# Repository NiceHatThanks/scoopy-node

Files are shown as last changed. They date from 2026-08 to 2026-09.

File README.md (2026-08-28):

# Scoopy Node

Tiny, local-first room hardware for Home Assistant and ESPHome.

Scoopy is a compact USB-C powered room controller built around an ESP32-C3. V1 combines two physical buttons, three PWM LEDs, optional LD2410C mmWave presence sensing, optional Home Assistant Bluetooth Proxy support, and an I²C expansion connection in a small 3D-printed enclosure.

There are two enclosure variants:

- **Scoopy Presence** — the full-size enclosure with an LD2410C mmWave presence sensor.
- **Scoopy Compact** — the smaller enclosure without the radar.

Both variants use the same firmware image. If an LD2410C is not fitted, the rest of Scoopy continues to work normally.

This repository contains the source-available hardware files, versioned STL enclosure exports, ESPHome firmware, captive-portal UI, manufacturing outputs, and project documentation.

## Quick links

- Website and product information: https://nicehatthanks.com
- First-time setup: https://nicehatthanks.com/setup/
- Interactive Home Assistant docs and examples: https://nicehatthanks.com/docs/
- Assembly guide: [`docs/assembly.md`](docs/assembly.md)
- Troubleshooting: [`docs/troubleshooting.md`](docs/troubleshooting.md)
- Bambu Studio / 3MF project: [Scoopy on MakerWorld](https://makerworld.com/en/models/3231250-scoopy-home-assistant-esphome-room-controller#profileId-3659818)

## Repository structure

```text
hardware/
  kicad/             Editable KiCad source files
  gerbers/           Fabrication-ready Gerbers and drill files
  bom/               Bill of materials and manufacturing exports

enclosure/
  compact/           Versioned STL exports for Scoopy Compact
  presence/          Versioned STL exports for Scoopy Presence
  build/             Assembly photos used by the build guide

firmware/
  esphome/           Unified ESPHome configuration and custom components
  captive-portal/    Source for the branded Wi-Fi setup page

docs/
  setup.md           First-time setup and Home Assistant pairing
  examples.md        Ready-made Home Assistant automations
  assembly.md        V1 enclosure assembly guide
  troubleshooting.md Common setup, firmware and hardware issues
```

## Firmware

`firmware/esphome/scoopy.yaml` is the unified production configuration for both Scoopy variants. The V1 firmware identifies itself as `1.0.0` through the ESPHome project version.

V1 features include:

- Unique `scoopy-XXXXXX` naming using the ESP32 MAC address
- Scoopy-branded local Wi-Fi provisioning with a captive portal
- ESPHome native API and Home Assistant discovery
- Two physical buttons exposed as `single`, `double`, and `hold` event entities
- Three individually dimmable PWM LED entities
- Individual pulse, flash, and alert LED effects
- Coordinated three-LED patterns including Circular Pulse, Comet, Breathe All, Heartbeat, Ping Pong, and Ripple
- Pulsing red Wi-Fi/setup indication and a brief green confirmation after connection
- LD2410C presence, moving-target, and still-target entities when the radar is fitted
- Optional Home Assistant Bluetooth Proxy, disabled by default
- Passive BLE scanning with one active proxy connection slot
- Website-hosted firmware updates through the Home Assistant **Firmware Update** entity
- Native ESPHome OTA support for local/development updates
- USB serial provisioning through Improv
- Wi-Fi signal, Wi-Fi percentage, IP address, uptime, ESPHome version, and Scoopy firmware diagnostics
- I²C expansion on GPIO5 (SDA) and GPIO7 (SCL)
- Physical Wi-Fi/factory recovery by holding both buttons for 10 seconds

The firmware deliberately uses one image for both variants. On Scoopy Compact, LD2410C entities may show as unavailable or Unknown because the radar is not fitted; this does not affect buttons, LEDs, Wi-Fi, OTA, Bluetooth Proxy, or the rest of the device.

## Home Assistant

Once Scoopy has joined the same network as Home Assistant, ESPHome discovery should find it automatically.

Ready-made automations are in [`docs/examples.md`](docs/examples.md). The examples cover:

- LED pattern control
- Button-controlled lighting
- Presence-controlled lighting
- Time-aware lighting
- Alarm reminders
- Status LEDs
- Multi-function room controls for lights, fans, and blinds

The interactive version at https://nicehatthanks.com/docs/ can take one of your Scoopy Entity IDs and fill the matching Scoopy prefix into the examples automatically.

## Setup and recovery

For normal first-time setup, use https://nicehatthanks.com/setup/ or [`docs/setup.md`](docs/setup.md).

A fresh or factory-reset Scoopy creates a Wi-Fi network named `scoopy-XXXXXX` with password `scoopy123`. Wi-Fi credentials are sent directly to Scoopy through its local setup page; no Scoopy cloud account is involved.

To clear saved Wi-Fi credentials and return to setup mode, hold both physical buttons together for 10 seconds. The middle red LED flashes rapidly near the end of the hold before the reset is performed.

## Firmware updates

Released firmware can be installed directly from Home Assistant through Scoopy's **Firmware Update** entity. Scoopy reads the update manifest hosted at:

`https://nicehatthanks.com/firmware/scoopy/manifest.json`

An OTA update preserves the device identity, saved Wi-Fi credentials, Home Assistant connection, and existing entity IDs.

## Enclosure and printing

GitHub contains the versioned raw STL exports for Scoopy Compact and Scoopy Presence.

The slicer-ready Bambu Studio / 3MF project is intentionally **not** duplicated in this repository. MakerWorld is the single maintained source for the Bambu project and print profile:

**[Scoopy on MakerWorld](https://makerworld.com/en/models/3231250-scoopy-home-assistant-esphome-room-controller#profileId-3659818)**

See [`enclosure/README.md`](enclosure/README.md) for the STL layout and [`docs/assembly.md`](docs/assembly.md) for assembly.

## Hardware overview

V1 uses a 28 × 28 mm carrier PCBA with:

- ESP32-C3 Super Mini
- 2 × tactile buttons
- 3 × LEDs with 2.2 kΩ series resistors
- Optional HLK-LD2410C mmWave presence sensor
- I²C expansion connection
- USB-C power through the ESP32-C3 module

Scoopy Presence uses the LD2410C and the larger enclosure. Scoopy Compact uses the same carrier and firmware without the radar.

Electrical design and manufacturing files are documented in [`hardware/README.md`](hardware/README.md).

## Assembly

The enclosure build is the same basic process for Compact and Presence: fit the heat-set insert, secure the PCBA, place the two buttons in the lid, then clip the base and lid together while aligning the three light pipes with the LEDs.

For Scoopy Presence, a nylon M2 screw is recommended near the LD2410C because a metal screw may affect the radar.

See the illustrated [`docs/assembly.md`](docs/assembly.md) guide.

## Release status

`v1.0.0` is the first formal Scoopy release. The V1 hardware, firmware, STL exports, documentation, and manufacturing files in that release tag form the reproducible V1 baseline.

Development on `main` may move ahead after the release. Use a release tag when reproducing a known version.

## Build your own

The hardware, firmware, and printable STL files are available so you can inspect Scoopy, build one for yourself, modify it, and experiment with your own non-commercial versions.

Commercial manufacture or sale requires prior permission from Nice Hat Thanks.

See [`LICENSE`](LICENSE) for the full terms.

## Licence

Scoopy is **source available for personal and non-commercial use**. You may inspect the files, build your own, modify them, and share non-commercial derivatives under the terms in [`LICENSE`](LICENSE).

Commercial manufacture, sale, or other commercial use requires prior written permission from Nice Hat Thanks.

Scoopy is not released under an open-source or open-hardware licence.

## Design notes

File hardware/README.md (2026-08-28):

# Hardware

Electrical design and manufacturing files for Scoopy Node.

## Structure

- `kicad/scoopy/` — editable KiCad project source
- `gerbers/v1/` — V1 fabrication-ready Gerber and drill files
- `gerbers/V1-Gerbers.zip` — upload-ready V1 Gerber archive
- `bom/v1/` — V1 bill of materials and manufacturing exports

The KiCad directory contains the editable design source. Generated fabrication outputs live separately so the project stays clean and manufacturing files are easy to identify.

Exported schematic PDFs are not currently committed as a separate directory. The editable schematic is part of the KiCad project; release-specific exports can be added when useful.

Third-party STEP/GLB models and standalone library components with redistribution restrictions are intentionally not included.

## Revisions

Manufacturing outputs should remain grouped by hardware revision (`v1/`, `v2/`, and so on). Releases and Git tags can then identify the exact set of files used for a known hardware build.

`v1.0.0` identifies the first production-frozen V1 hardware baseline. Development on `main` may continue after that tag, so use a release/tag when reproducing a known hardware build.

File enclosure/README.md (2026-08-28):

# Enclosure

Printable enclosure files for Scoopy Node.

Scoopy has two enclosure variants:

- `compact/` — the smaller enclosure without presence sensing
- `presence/` — the larger enclosure designed for the mmWave presence version

Each variant is organised the same way:

```text
<variant>/
  stl/
    v1/
      full/      complete enclosure STL export
      parts/     individual printable components
```

## Bambu Studio / 3MF project

The slicer-ready Bambu Studio / 3MF project is intentionally **not** tracked in this repository.

MakerWorld is the single maintained source for the Bambu project and print profile:

**[Scoopy on MakerWorld](https://makerworld.com/en/models/3231250-scoopy-home-assistant-esphome-room-controller#profileId-3659818)**

This avoids having separate GitHub and MakerWorld copies drift apart over time. GitHub remains the source for the versioned raw STL exports; MakerWorld is the source for the maintained Bambu slicer project/profile.

Fusion source files are intentionally not published. The public enclosure files are focused on making it straightforward to print a complete enclosure or replace individual parts.

Keep printable STL exports grouped by enclosure revision so a known release can always be reproduced later.

## V1 filenames

The committed V1 exports use these names:

```text
scoopy-compact-v1-complete.stl
scoopy-compact-v1-base.stl
scoopy-compact-v1-lid.stl
scoopy-compact-v1-button1.stl
scoopy-compact-v1-button2.stl
scoopy-compact-v1-lightpipe-1.stl
scoopy-compact-v1-lightpipe-2.stl
scoopy-compact-v1-lightpipe-3.stl

scoopy-presence-v1-complete.stl
scoopy-presence-v1-base.stl
scoopy-presence-v1-lid.stl
scoopy-presence-v1-button1.stl
scoopy-presence-v1-button2.stl
scoopy-presence-v1-lightpipe-1.stl
scoopy-presence-v1-lightpipe-2.stl
scoopy-presence-v1-lightpipe-3.stl
```

For assembly, see [`../docs/assembly.md`](../docs/assembly.md).

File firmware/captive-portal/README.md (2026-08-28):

# Captive portal

This directory contains the human-readable source for Scoopy's branded first-time Wi-Fi setup page.

## Files

- `index.html` — standalone source for the Scoopy captive-portal UI

The production ESPHome firmware uses a local captive-portal component under `../esphome/components/` so ESPHome's normal provisioning behaviour can be retained while presenting the Scoopy setup UI.

## Relationship to the firmware

The production device configuration lives in `../esphome/scoopy.yaml`.

On a fresh or factory-reset device, Scoopy creates a `scoopy-XXXXXX` Wi-Fi access point. After the user connects, the captive portal is used to select the home Wi-Fi network and provide its credentials.

The production firmware deliberately does not compile a customer's Wi-Fi credentials into the image.

The V1 provisioning flow has been validated on hardware for first-time setup and recovery and is part of the `v1.0.0` firmware baseline.

## Editing

Treat `index.html` as the human-readable source for the setup page. The copy served by firmware is embedded in `../esphome/components/captive_portal/scoopy_index.h`.

When changing the captive-portal UI, keep the human-readable HTML and embedded firmware copy in sync, then re-test both fresh-device onboarding and the 10-second physical factory-reset flow before releasing the change.

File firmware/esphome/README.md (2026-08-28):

# ESPHome firmware

This directory contains the unified ESPHome production firmware for Scoopy.

Scoopy Presence and Scoopy Compact use the same `scoopy.yaml` configuration. Scoopy Presence includes the LD2410C mmWave radar; Scoopy Compact omits it. When no LD2410C is fitted, the rest of the device continues to operate normally.

## Files

- `scoopy.yaml` — unified production ESPHome configuration
- `components/` — local ESPHome component overrides used by Scoopy
- `.gitignore` — prevents local ESPHome build output and secrets from being committed

The human-readable branded captive-portal HTML source is kept separately in `../captive-portal/`.

## Pinout

| GPIO | Function |
| --- | --- |
| GPIO0 | ESP RX ← LD2410C TX |
| GPIO1 | ESP TX → LD2410C RX |
| GPIO2 | Button 1 |
| GPIO3 | Button 2 |
| GPIO4 | Left green LED |
| GPIO5 | I²C SDA |
| GPIO6 | Middle red LED |
| GPIO7 | I²C SCL |
| GPIO10 | Right green LED |

## First-time provisioning

A fresh or factory-reset Scoopy starts its own Wi-Fi access point named `scoopy-XXXXXX`, where the suffix comes from the ESP32 MAC address.

1. Power Scoopy over USB-C.
2. Connect to the `scoopy-XXXXXX` Wi-Fi network.
3. Use the setup password `scoopy123`.
4. Enter the home Wi-Fi credentials in the Scoopy captive portal.
5. After Scoopy joins Wi-Fi, the red setup indication stops and both green LEDs give a brief confirmation flash.
6. Home Assistant should then discover Scoopy through the ESPHome integration.

Provisioning over USB serial using ESPHome Improv is also enabled.

## Recovery

Hold both physical buttons together for 10 seconds to clear the saved Wi-Fi credentials and return Scoopy to setup mode. The middle red LED flashes rapidly near the end of the hold before the reset is performed.

## Firmware behaviour

The V1 production configuration provides:

- MAC-suffixed `scoopy-XXXXXX` device names so one firmware image can be flashed to multiple units
- ESPHome native API integration and Home Assistant discovery
- native ESPHome OTA support for local/development updates
- website-hosted HTTP firmware updates through the Home Assistant **Firmware Update** entity
- two physical button entities with `single`, `double`, and `hold` events
- three individually dimmable PWM LED entities
- individual LED effects plus coordinated three-LED patterns including Circular Pulse, Comet, Breathe All, Heartbeat, Ping Pong, and Ripple
- a bright pulsing middle red LED while Scoopy is waiting for Wi-Fi or disconnected
- a brief two-green-LED confirmation after Wi-Fi connects
- LD2410C Presence, Moving Target, and Still Target entities when the radar is fitted
- LD2410 distance entities intentionally disabled by default to avoid unnecessary high-frequency Home Assistant Recorder history
- graceful operation without radar on Scoopy Compact
- optional Home Assistant Bluetooth Proxy, disabled by default and remembered across reboots
- passive BLE scanning with one active proxy connection slot when Bluetooth Proxy is enabled
- Wi-Fi signal, Wi-Fi percentage, IP address, uptime, ESPHome version, and Scoopy firmware diagnostics
- USB serial provisioning through Improv
- a generic I²C expansion bus on GPIO5/GPIO7
- physical Wi-Fi/factory recovery by holding both buttons for 10 seconds

## Building and flashing

The production configuration intentionally does not contain a home Wi-Fi SSID or password. Credentials are provisioned after flashing.

From an ESPHome environment, build or flash `scoopy.yaml` in the usual way. Local ESPHome build artefacts, compiled release binaries, production tooling, and secrets should remain untracked.

`v1.0.0` establishes the first formal Scoopy firmware baseline. Future released firmware should increment the Scoopy project version using semantic versioning, with the corresponding Git tag preserving the exact source used for that release.

## Licence

Scoopy-specific firmware configuration and project material are covered by the repository's source-available, non-commercial [`LICENSE`](../../LICENSE). Personal builds and modifications are welcome; commercial use requires prior permission from Nice Hat Thanks.

The local `components/captive_portal/` override includes code derived from ESPHome and therefore retains the applicable upstream ESPHome licence terms. See [`components/captive_portal/THIRD_PARTY_NOTICE.md`](components/captive_portal/THIRD_PARTY_NOTICE.md).

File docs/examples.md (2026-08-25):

# Home Assistant examples

These examples are starting points for Scoopy automations in Home Assistant.

For an interactive version that can fill your Scoopy and other entity IDs into the YAML automatically, use **https://nicehatthanks.com/docs/**.

## Before you copy

### Find your Scoopy Entity ID

In Home Assistant:

1. Go to **Settings → Devices & services**.
2. Open your **Scoopy**.
3. Open an entity such as **Button 1**.
4. Select the **cog/settings icon**.
5. Copy the full **Entity ID**.

You may see something like:

```text
event.study_scoopy_test_button_1
```

Home Assistant may include your assigned **area** in the Entity ID. For example, a Scoopy called `scoopy_test` assigned to the Study may use `study_scoopy_test` as the shared entity prefix.

For these examples, replace:

```text
scoopy_xxxxxx
```

with the shared Scoopy part:

```text
study_scoopy_test
```

So:

```text
event.scoopy_xxxxxx_button_1
```

becomes:

```text
event.study_scoopy_test_button_1
```

You can use the same shared prefix for the Scoopy buttons, LEDs, LED Pattern and presence entities.

> Tip: You can also paste an example into **Edit in YAML** in Home Assistant, then switch back to the visual editor and use Home Assistant's normal entity pickers to choose your lights, fans, blinds, sensors and other devices.

---

## 1. Try Scoopy's LEDs

**Button 1** starts the Circular Pulse effect. **Button 2** stops it.

Change only `scoopy_xxxxxx`.

```yaml
alias: Scoopy - Circular Pulse Demo
description: Button 1 starts the circular pulse, Button 2 stops it

triggers:
  # Scoopy Button 1 - single press
  - trigger: event.received
    target:
      entity_id: event.scoopy_xxxxxx_button_1
    options:
      event_type:
        - single
    id: pulse_on

  # Scoopy Button 2 - single press
  - trigger: event.received
    target:
      entity_id: event.scoopy_xxxxxx_button_2
    options:
      event_type:
        - single
    id: pulse_off

conditions: []

actions:
  - choose:
      # Button 1 -> start the coordinated Circular Pulse effect
      - conditions:
          - condition: trigger
            id: pulse_on
        sequence:
          - action: light.turn_on
            target:
              entity_id: light.scoopy_xxxxxx_led_pattern
            data:
              effect: Circular Pulse

      # Button 2 -> stop the pattern and turn the LEDs off
      - conditions:
          - condition: trigger
            id: pulse_off
        sequence:
          - action: light.turn_off
            target:
              entity_id: light.scoopy_xxxxxx_led_pattern

mode: restart
```

## 2. Press a button to turn on a light

Press **Button 1** to turn a light on. Press it again to turn the same light off.

Change `scoopy_xxxxxx` and `light.your_light`.

```yaml
alias: Scoopy - Button 1 Toggle Light
description: Button 1 toggles a Home Assistant light on and off

triggers:
  # Scoopy Button 1 - single press
  - trigger: event.received
    target:
      entity_id: event.scoopy_xxxxxx_button_1
    options:
      event_type:
        - single

conditions: []

actions:
  # Works with Hue or any other light exposed to Home Assistant
  - action: light.toggle
    target:
      entity_id: light.your_light

mode: restart
```

## 3. Turn the room light on when you're there

Presence turns the light on immediately. Leave the room for **5 seconds** and it turns off.

Change `scoopy_xxxxxx` and `light.your_light`. Increase the 5-second delay if you want a slower switch-off.

```yaml
alias: Scoopy - Presence Controlled Light
description: Presence turns the light on, 5 seconds with no presence turns it off

triggers:
  # Someone is detected -> turn the light on
  - trigger: state
    entity_id: binary_sensor.scoopy_xxxxxx_presence
    from: "off"
    to: "on"
    id: presence_on

  # Nobody detected for 5 seconds -> turn the light off
  - trigger: state
    entity_id: binary_sensor.scoopy_xxxxxx_presence
    from: "on"
    to: "off"
    for:
      seconds: 5
    id: presence_off

conditions: []

actions:
  - choose:
      - conditions:
          - condition: trigger
            id: presence_on
        sequence:
          - action: light.turn_on
            target:
              entity_id: light.your_light

      - conditions:
          - condition: trigger
            id: presence_off
        sequence:
          - action: light.turn_off
            target:
              entity_id: light.your_light

mode: restart
```

## 4. Make the lights softer at night

If the light is off, **Button 1** turns it on at **100%** during the day or **25%** from 9pm to 7am. If the light is already on, Button 1 turns it off.

Change `scoopy_xxxxxx` and `light.your_light`. Change the times and brightness percentages to suit your room.

```yaml
alias: Scoopy - Time Aware Light Button
description: Button 1 toggles a light, using a dimmer brightness at night

triggers:
  # Scoopy Button 1 - single press
  - trigger: event.received
    target:
      entity_id: event.scoopy_xxxxxx_button_1
    options:
      event_type:
        - single

conditions: []

actions:
  - choose:
      # If the light is already on, turn it off
      - conditions:
          - condition: state
            entity_id: light.your_light
            state: "on"
        sequence:
          - action: light.turn_off
            target:
              entity_id: light.your_light

      # If it is 9pm-7am, turn it on dimly
      - conditions:
          - condition: or
            conditions:
              - condition: time
                after: "21:00:00"
              - condition: time
                before: "07:00:00"
        sequence:
          - action: light.turn_on
            target:
              entity_id: light.your_light
            data:
              brightness_pct: 25

    # Otherwise it is daytime -> turn it on at full brightness
    default:
      - action: light.turn_on
        target:
          entity_id: light.your_light
        data:
          brightness_pct: 100

mode: restart
```

## 5. Remind me if the alarm isn't set

At **10pm**, if your alarm is still disarmed, Scoopy starts a gentle **Heartbeat** pattern. Arm the alarm and the reminder stops.

Change `scoopy_xxxxxx` and `alarm_control_panel.your_alarm`. Adjust the times if you want different reminder hours.

```yaml
alias: Scoopy - Alarm Reminder
description: Heartbeat at night while the alarm is disarmed

triggers:
  # Check automatically at 10pm
  - trigger: time
    at: "22:00:00"
    id: reminder_start

  # Re-check whenever the alarm state changes
  - trigger: state
    entity_id: alarm_control_panel.your_alarm
    id: alarm_changed

  # Stop any reminder at 5am
  - trigger: time
    at: "05:00:00"
    id: reminder_end

conditions: []

actions:
  - choose:
      # During reminder hours, show Heartbeat while the alarm is disarmed
      - conditions:
          - condition: state
            entity_id: alarm_control_panel.your_alarm
            state: "disarmed"
          - condition: or
            conditions:
              - condition: time
                after: "22:00:00"
              - condition: time
                before: "05:00:00"
        sequence:
          - action: light.turn_on
            target:
              entity_id: light.scoopy_xxxxxx_led_pattern
            data:
              effect: Heartbeat

    # Alarm armed, or reminder hours finished -> stop the pattern
    default:
      - action: light.turn_off
        target:
          entity_id: light.scoopy_xxxxxx_led_pattern

mode: restart
```

## 6. Show me if something is still open

When a door, garage or other binary sensor is open, Scoopy's **middle red LED** turns on. Close it and the LED turns off.

Change `scoopy_xxxxxx` and `binary_sensor.your_door`. For most contact sensors, `on` means open.

```yaml
alias: Scoopy - Door Open Status
description: Red LED stays on while a door or other sensor is open

triggers:
  - trigger: state
    entity_id: binary_sensor.your_door
    id: door_changed

conditions: []

actions:
  - if:
      - condition: state
        entity_id: binary_sensor.your_door
        state: "on"
    then:
      - action: light.turn_on
        target:
          entity_id: light.scoopy_xxxxxx_middle_led
        data:
          brightness_pct: 100
    else:
      - action: light.turn_off
        target:
          entity_id: light.scoopy_xxxxxx_middle_led

mode: restart
```

## 7. Make each button do more

**Button 1:** press to toggle a fan, hold to open or close the blinds.  
**Button 2:** press for time-aware lighting, hold for full brightness.

Change `scoopy_xxxxxx`, `switch.your_fan`, `cover.your_blind` and `light.your_light`.

```yaml
alias: Scoopy - Whole Room Controls
description: Fan, blinds and time-aware lighting controlled by Scoopy

triggers:
  # Button 1 - press -> fan
  - trigger: event.received
    target:
      entity_id: event.scoopy_xxxxxx_button_1
    options:
      event_type:
        - single
    id: fan_toggle

  # Button 1 - hold -> blinds
  - trigger: event.received
    target:
      entity_id: event.scoopy_xxxxxx_button_1
    options:
      event_type:
        - hold
    id: blinds_toggle

  # Button 2 - press -> time-aware light
  - trigger: event.received
    target:
      entity_id: event.scoopy_xxxxxx_button_2
    options:
      event_type:
        - single
    id: light_toggle

  # Button 2 - hold -> maximum brightness
  - trigger: event.received
    target:
      entity_id: event.scoopy_xxxxxx_button_2
    options:
      event_type:
        - hold
    id: light_full

conditions: []

actions:
  - choose:
      # Button 1 press -> toggle the fan
      - conditions:
          - condition: trigger
            id: fan_toggle
        sequence:
          - action: switch.toggle
            target:
              entity_id: switch.your_fan

      # Button 1 hold -> open closed blinds, otherwise close them
      - conditions:
          - condition: trigger
            id: blinds_toggle
        sequence:
          - if:
              - condition: template
                value_template: >
                  {{ state_attr('cover.your_blind', 'current_position') | int(0) == 0 }}
            then:
              - action: cover.open_cover
                target:
                  entity_id: cover.your_blind
            else:
              - action: cover.close_cover
                target:
                  entity_id: cover.your_blind

      # Button 2 press -> toggle the room light
      - conditions:
          - condition: trigger
            id: light_toggle
        sequence:
          - if:
              - condition: state
                entity_id: light.your_light
                state: "on"
            then:
              - action: light.turn_off
                target:
                  entity_id: light.your_light
                data:
                  transition: 1
            else:
              - choose:
                  # 5am-6:30pm -> bright
                  - conditions:
                      - condition: time
                        after: "05:00:00"
                        before: "18:30:00"
                    sequence:
                      - action: light.turn_on
                        target:
                          entity_id: light.your_light
                        data:
                          brightness_pct: 100
                          transition: 1

                  # 6:30pm-10pm -> softer
                  - conditions:
                      - condition: time
                        after: "18:30:00"
                        before: "22:00:00"
                    sequence:
                      - action: light.turn_on
                        target:
                          entity_id: light.your_light
                        data:
                          brightness_pct: 35
                          transition: 1

                  # 10pm-5am -> very dim
                  - conditions:
                      - condition: or
                        conditions:
                          - condition: time
                            after: "22:00:00"
                          - condition: time
                            before: "05:00:00"
                    sequence:
                      - action: light.turn_on
                        target:
                          entity_id: light.your_light
                        data:
                          brightness_pct: 5
                          transition: 1

      # Button 2 hold -> force full brightness
      - conditions:
          - condition: trigger
            id: light_full
        sequence:
          - action: light.turn_on
            target:
              entity_id: light.your_light
            data:
              brightness_pct: 100
              transition: 0.5

mode: restart
```

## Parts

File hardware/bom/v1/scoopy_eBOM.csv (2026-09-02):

Reference | Qty | Value | DNP | MPN | Footprint | Datasheet | Supplier | Link | Supplier_PN
J3 | 1 | Conn_01x04_Pin | DNP |  | Connector_PinHeader_2.54mm:PinHeader_1x04_P2.54mm_Vertical | https://4donline.ihs.com/images/VipMasterIC/IC/MOLE/MOLES37362/MOLE-S-A0011124653-1.pdf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 | Farnell | https://uk.farnell.com/molex/42375-1246/connector-header-4pos-1row-2-54mm/dp/3049569 | 3049569
R1,R2,R3 | 3 | 2.2k |  | C2907002 | Resistor_SMD:R_0603_1608Metric | https://4donline.ihs.com/images/VipMasterIC/IC/SCMP/SCMP-S-A0009547702/SCMP-S-A0009547702-1.pdf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 | Farnell | https://uk.farnell.com/multicomp-pro/mcwr06x2201ftl/res-2k2-1-0-1w-0603-thick-film/dp/2447320 | MCWR06X2201FTL
SW1,SW2 | 2 | SW_Push |  | C879462 | Button_Switch_SMD:SW_SPST_TL3305C | https://uk.farnell.com/e-switch/tl3305cf260qg/tactile-switch-0-05a-12vdc-smd/dp/4051109 | Farnell | https://uk.farnell.com/e-switch/tl3305cf260qg/tactile-switch-0-05a-12vdc-smd/dp/4051109 | 4051109
J1 | 1 | ESP32_SuperMini |  |  | StyxLib:ESP32-C3-SuperMini | https://www.espboards.dev/esp32/esp32-c3-super-mini/ | Amazon | https://www.amazon.co.uk/Youmile-Development-SuperMini-Bluetooth-Frequency/dp/B0D2WSYRZM | N/A
D3 | 1 | LED - Red |  | C19171390 | LED_SMD:LED_0603_1608Metric | https://www.farnell.com/datasheets/3497874.pdf | Farnell | https://uk.farnell.com/multicomp-pro/mp008277/led-red-220mcd-626nm-0603/dp/3796306 | 3796306
D1,D2 | 2 | LED - Green |  | C22371297 | LED_SMD:LED_0603_1608Metric | https://www.farnell.com/datasheets/3497885.pdf | Farnell | https://uk.farnell.com/multicomp-pro/mp008288/led-green-90mcd-577nm-0603/dp/3796319 | 3796319
J2 | 1 | LD2410C |  |  | StyxLib:Ld2410c | https://www.scribd.com/document/990062283/HLK-LD2410C-Life-Presence-Sensor-Module-Data-Sheet-V1-00 | Amazon | https://www.amazon.co.uk/DollaTek-Ld2410c-Presence-Detection-Security/dp/B0F25WTY1W | N/A

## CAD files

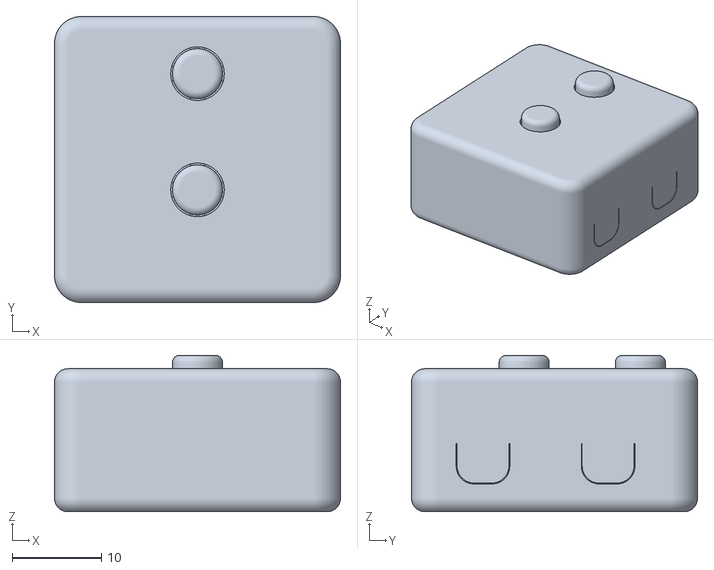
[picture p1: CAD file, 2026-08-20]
enclosure/compact/stl/v1/full/scoopy-compact-v1-complete.stl
32.0 x 32.0 x 17.5

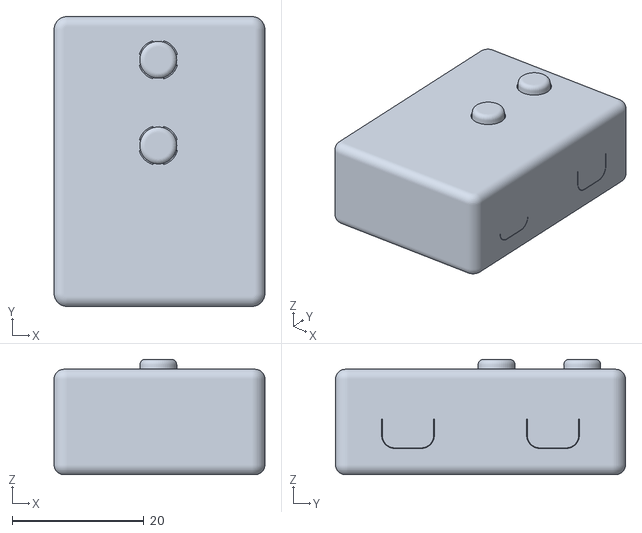
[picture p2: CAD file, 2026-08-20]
enclosure/presence/stl/v1/full/scoopy-presence-v1-complete.stl
32.0 x 44.0 x 17.5

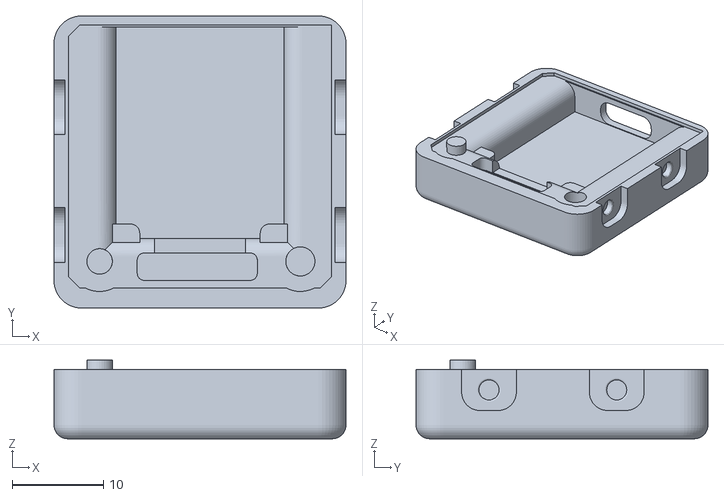
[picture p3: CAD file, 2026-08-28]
enclosure/compact/stl/v1/parts/scoopy-compact-v1-base.stl
32.0 x 32.0 x 8.62

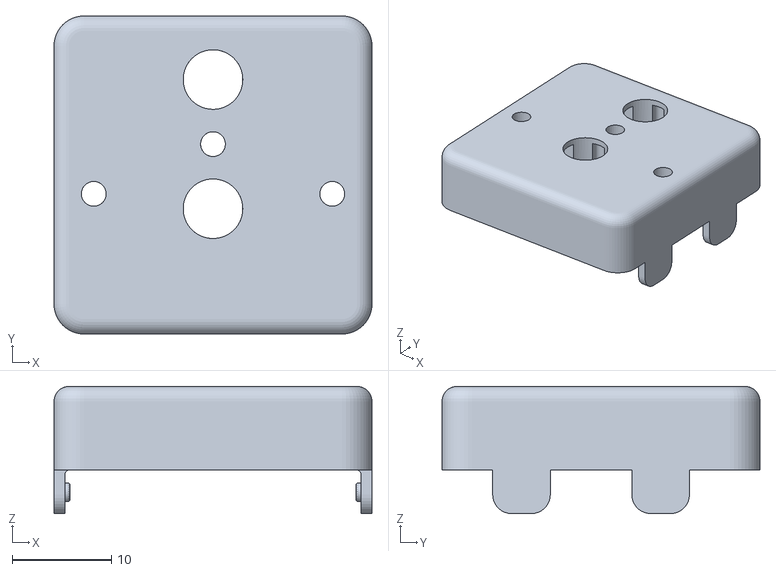
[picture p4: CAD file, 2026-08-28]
enclosure/compact/stl/v1/parts/scoopy-compact-v1-lid.stl
32.0 x 32.0 x 12.8

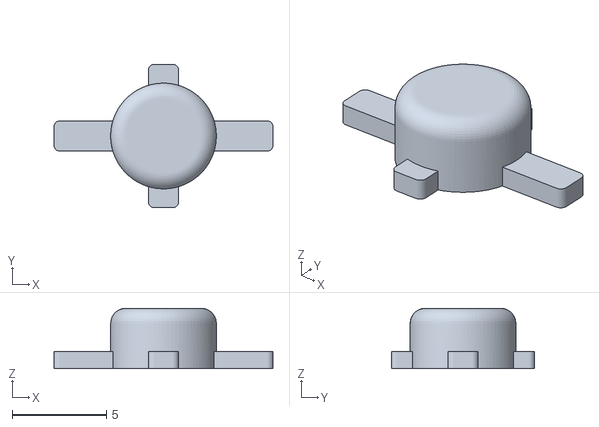
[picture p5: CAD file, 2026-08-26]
enclosure/presence/stl/v1/parts/scoopy-presence-v1-button1.stl
11.6 x 7.60 x 3.20

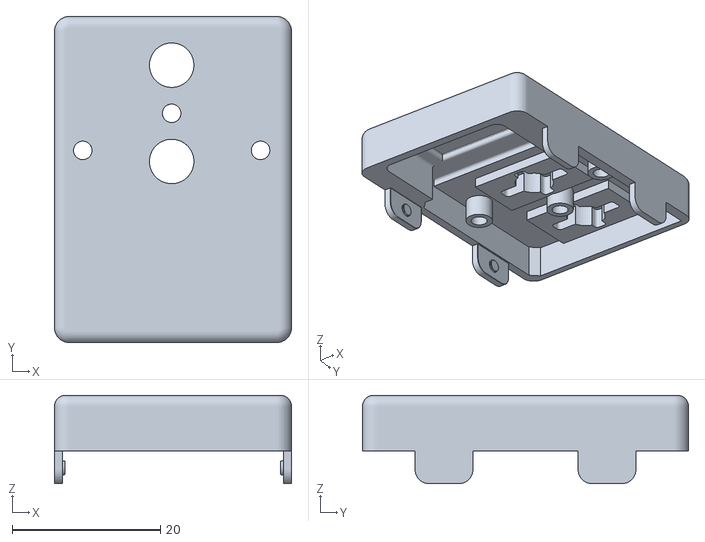
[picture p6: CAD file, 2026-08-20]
enclosure/presence/stl/v1/parts/scoopy-presence-v1-lid.stl
32.0 x 44.0 x 11.9

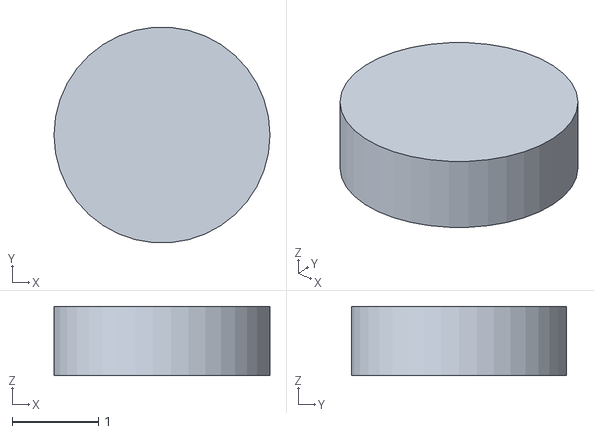
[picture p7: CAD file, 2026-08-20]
enclosure/compact/stl/v1/parts/scoopy-compact-v1-lightpipe-3.stl
2.50 x 2.49 x 0.8

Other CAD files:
enclosure/presence/stl/v1/parts/scoopy-presence-v1-lightpipe-3.stl
enclosure/compact/stl/v1/parts/scoopy-compact-v1-lightpipe-2.stl
enclosure/presence/stl/v1/parts/scoopy-presence-v1-lightpipe-2.stl
enclosure/compact/stl/v1/parts/scoopy-compact-v1-lightpipe-1.stl
enclosure/presence/stl/v1/parts/scoopy-presence-v1-lightpipe-1.stl

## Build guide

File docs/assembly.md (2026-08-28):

# Scoopy assembly

Assembly is the same for **Scoopy** and **Scoopy Compact**. The Presence version simply has the LD2410C fitted to the PCBA.

If you are printing your own enclosure, use the versioned STL exports in [`../enclosure/`](../enclosure/) or the maintained [Scoopy MakerWorld project](https://makerworld.com/en/models/3231250-scoopy-home-assistant-esphome-room-controller#profileId-3659818) for the Bambu Studio / 3MF profile.

## What you need

- 1 × M2 brass heat-set insert
- 1 × M2 × 6 mm screw
  - For Scoopy Presence, use a **nylon screw** where possible. A metal screw may affect the LD2410C radar.
- 1 × Scoopy PCBA
- 1 × Scoopy base
- 1 × Scoopy lid
- 2 × Scoopy buttons

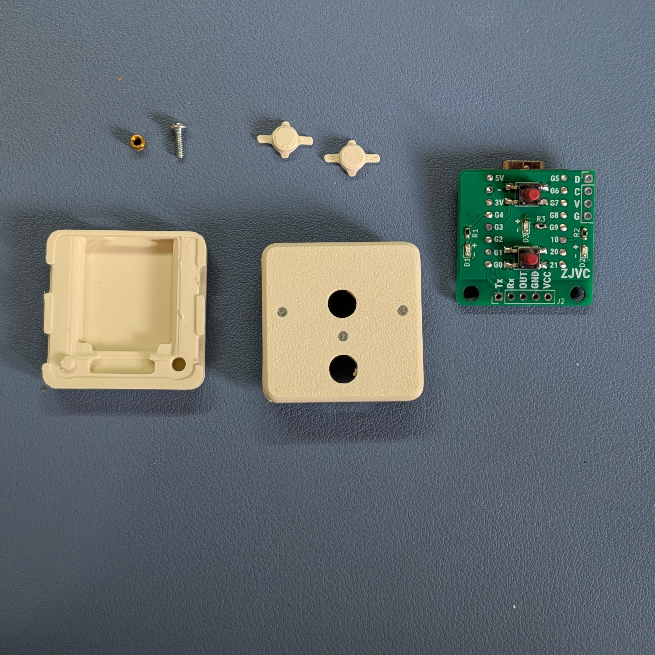
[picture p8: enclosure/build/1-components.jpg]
Scoopy assembly components


## 1. Fit the brass insert

Heat-set the M2 brass insert into the hole in the Scoopy base. Make sure it sits straight and allow it to cool fully before continuing.

## 2. Fit the PCBA

Slide the USB-C connector into the opening in the base, then lower the PCBA into position.

Secure the PCBA by threading the M2 × 6 mm screw into the brass insert.

> **Scoopy Presence:** use a nylon screw where possible. A metal screw close to the LD2410C may affect the radar.

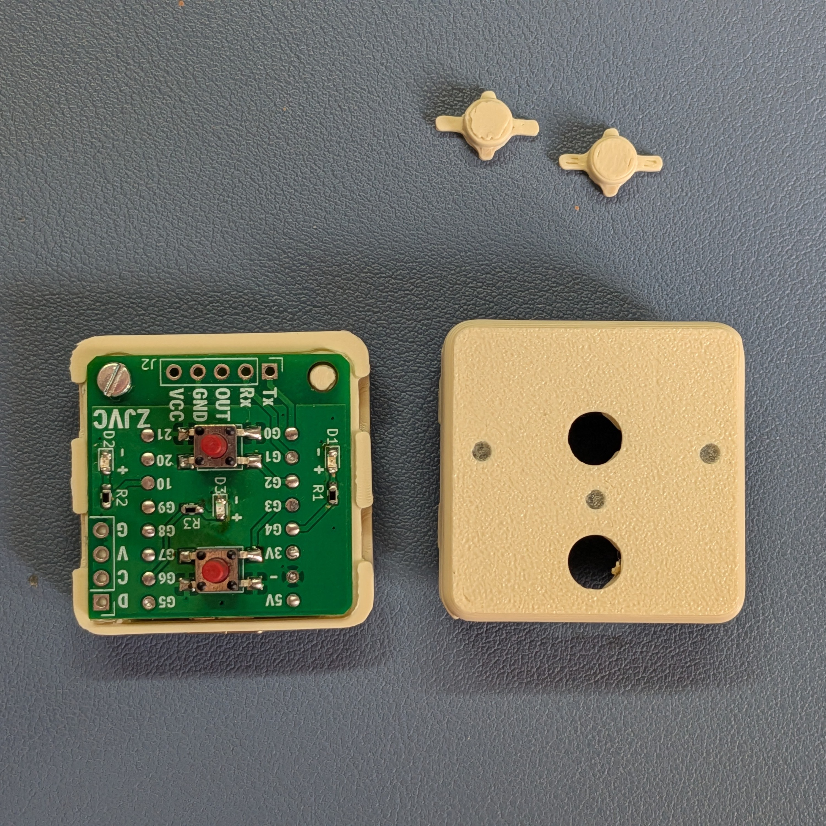
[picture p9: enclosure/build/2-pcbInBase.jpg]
Scoopy PCBA fitted into the base


## 3. Fit the buttons

Place both Scoopy buttons into the lid in their openings.

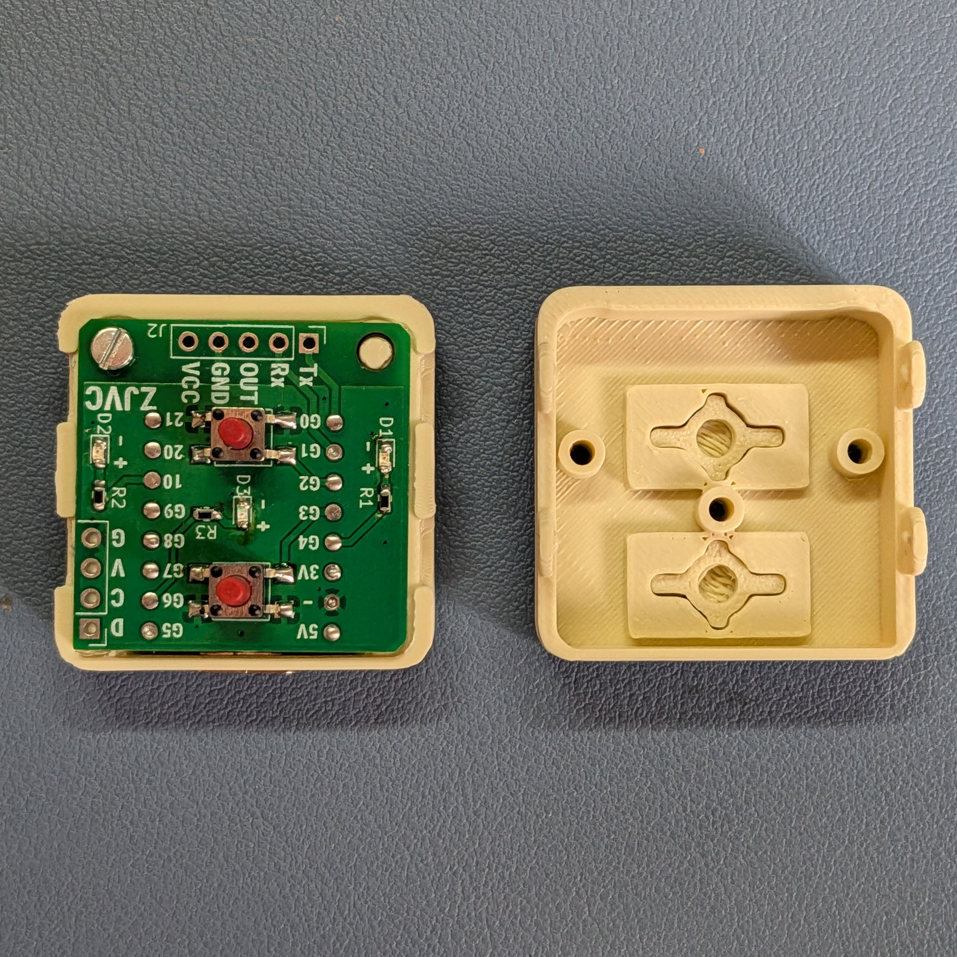
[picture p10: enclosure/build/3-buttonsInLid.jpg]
Scoopy buttons fitted into the lid


## 4. Close Scoopy

Push the base into the lid until it clips into place.

Check the orientation before pushing the two halves together: the lid's three light pipes must line up with the three LEDs on the PCBA.

## 5. Done

That's it — Scoopy is assembled.

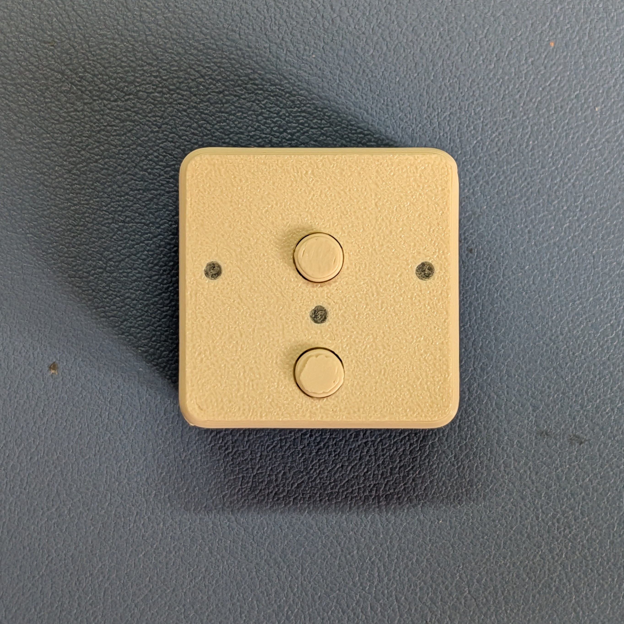
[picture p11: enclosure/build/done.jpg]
Completed Scoopy


## Set up Scoopy

Now you've built your Scoopy, head to the [Scoopy setup guide](https://nicehatthanks.com/setup/) to get it connected and running.

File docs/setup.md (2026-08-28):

# Setup

This guide covers first-time setup of Scoopy with Wi-Fi, ESPHome, and Home Assistant.

Scoopy and Scoopy Compact use the same setup process and the same firmware image.

## What you need

- A Scoopy flashed with the current firmware
- A USB-C power supply and cable
- A 2.4 GHz Wi-Fi network available to the device
- Home Assistant with the ESPHome integration available

Scoopy setup stays local. Your Wi-Fi details are sent directly to the Scoopy you are connected to; there is no Scoopy cloud account involved in onboarding.

## First-time Wi-Fi setup

1. Power Scoopy over USB-C.
2. If it has no saved Wi-Fi network, the middle red LED begins pulsing. This means Scoopy is ready for setup.
3. On your phone, tablet, or computer, open Wi-Fi settings and connect to a network named `scoopy-XXXXXX`.
4. Enter the setup password `scoopy123`.
5. The Scoopy setup page should open automatically.
6. Select your home Wi-Fi network, enter its password, then press **Connect Scoopy**.
7. Once the connection succeeds, the setup page shows **Connected**. It is also normal for the page to disappear as Scoopy leaves setup mode.
8. The middle red setup LED turns off. Scoopy gives a brief green confirmation flash after joining Wi-Fi, then leaves the LEDs off for normal operation.

The final six characters in `scoopy-XXXXXX` come from the ESP32 MAC address, so each Scoopy has a unique setup network and device name.

### If the setup page does not open

Captive portals behave slightly differently between phones, tablets, and computers.

- Make sure your device is still connected to `scoopy-XXXXXX`, not your normal home Wi-Fi.
- A **No internet** warning is expected. Scoopy's temporary setup network is local only.
- On some tablets, open the Wi-Fi network details and choose **Manage router** or **Sign in to network**.
- If a computer opens a Microsoft connectivity page, gets stuck, or does not show the Scoopy page correctly, use a phone or tablet for this part of setup.

For more checks, see [`troubleshooting.md`](troubleshooting.md).

## Add Scoopy to Home Assistant

Once Scoopy has joined the same network as Home Assistant, ESPHome discovery should find it automatically.

1. Open Home Assistant.
2. Look for the discovered Scoopy device, either on a discovery card or under **Settings → Devices & services**.
3. Select **Add** on the discovered ESPHome device.
4. Confirm the prompt with **Submit**.
5. Give the device a useful name, such as **Scoopy - Office**, and assign it to a Home Assistant area if you want to.
6. Open the new Scoopy device page and confirm the expected entities are available.

Home Assistant may include your chosen device name and area in generated Entity IDs. That is normal and is why the examples guide asks you to check the actual Entity ID used by your own Scoopy.

## What should appear in Home Assistant

All Scoopies expose:

- **Button 1** and **Button 2** event entities with `single`, `double`, and `hold` events
- **Left LED**, **Middle LED**, and **Right LED** light entities
- **LED Pattern** for coordinated three-LED effects
- **Bluetooth Proxy** under Configuration, switched off by default
- **Firmware Update** for released OTA updates
- Wi-Fi, IP, uptime, ESPHome version, and Scoopy firmware diagnostic entities

Scoopy Presence also exposes LD2410C mmWave entities including:

- Presence
- Moving Target
- Still Target

Scoopy Compact uses the same firmware without the LD2410C fitted. Radar entities may therefore show as unavailable or Unknown; this is expected and the rest of the device continues to work normally.

## Bluetooth Proxy

Bluetooth Proxy is optional and starts switched off.

To enable it, open your Scoopy in Home Assistant and turn on **Bluetooth Proxy** under Configuration. The setting is remembered across reboots.

Scoopy uses passive BLE scanning and provides one active proxy connection slot. If Home Assistant disconnects, BLE scanning stops automatically and resumes after Home Assistant reconnects when the switch is still enabled.

More detail is available at https://nicehatthanks.com/docs/#bluetooth.

## Firmware updates

When a newer released firmware version is available, Home Assistant shows it through the **Firmware Update** entity on the Scoopy device page.

Open the entity and choose **Install**. Scoopy downloads the firmware over Wi-Fi and reboots automatically.

Normal OTA updates preserve:

- Wi-Fi credentials
- Home Assistant connection
- Device identity
- Existing entity IDs and automations

## USB provisioning

ESPHome Improv over serial is enabled as an alternative way to provide Wi-Fi credentials while Scoopy is connected over USB.

## Reset Wi-Fi credentials

You do not need to reflash Scoopy to change Wi-Fi networks.

1. Press and hold both physical buttons together for 10 seconds.
2. During the final part of the hold, the middle red LED flashes rapidly to warn that a factory reset is about to happen.
3. Scoopy clears its saved Wi-Fi credentials and reboots into setup mode.
4. The middle red LED begins pulsing again and the `scoopy-XXXXXX` setup network returns.

Holding both buttons is reserved for recovery, so avoid holding both together for 10 seconds during normal use.

## After setup

Ready-made Home Assistant automations are in [`examples.md`](examples.md).

For the easiest version, use https://nicehatthanks.com/docs/. Its interactive examples can take one of your Scoopy Entity IDs and fill the matching Scoopy prefix into the examples automatically.

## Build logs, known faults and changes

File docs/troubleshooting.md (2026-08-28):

# Troubleshooting

This guide covers the most common V1 setup, firmware, hardware, and enclosure problems.

If Scoopy is already assembled, start with the simple checks first: known-good USB power, Wi-Fi setup state, Home Assistant discovery, and a reboot. If something is visibly damaged, smells hot, or is getting unusually warm, disconnect power and inspect the hardware before continuing.

## Device does not power on

- Try a known-good USB-C cable and USB power source.
- Check that the ESP32-C3 module is seated and soldered correctly to the Scoopy carrier PCB.
- Inspect the USB-C connector and nearby solder joints for damage or shorts.
- If you assembled Scoopy yourself, remove the enclosure and confirm the PCB is not being mechanically stressed by the case or screw.
- If the board becomes unusually hot, disconnect it immediately and inspect for a short or assembly fault.

A working Scoopy with no saved Wi-Fi should boot into setup mode and pulse the middle red LED.

## Scoopy is not discovered by Home Assistant

First confirm Scoopy has successfully joined your normal Wi-Fi. The middle red setup pulse should stop after connection and Scoopy gives a brief green confirmation flash.

Then:

- Make sure Home Assistant and Scoopy are on networks that can communicate with each other.
- Open **Settings → Devices & services** and check for a discovered ESPHome device.
- Give discovery a short moment after Scoopy joins Wi-Fi or reboots.
- If it is not discovered automatically, find Scoopy's IP address from your router or from ESPHome logs and add the ESPHome integration manually using that address.
- Rebooting Scoopy and Home Assistant discovery can also clear a stale discovery state.

If Scoopy has fallen back into setup mode and the red LED is pulsing, fix Wi-Fi first.

## Wi-Fi provisioning problems

Scoopy only uses 2.4 GHz Wi-Fi.

During first-time setup:

- Connect to `scoopy-XXXXXX` using password `scoopy123`.
- Ignore warnings that the setup network has **No internet**. That is expected.
- Make sure your phone/tablet/computer remains connected to Scoopy rather than automatically switching back to your normal Wi-Fi.
- On some tablets, open the network details and choose **Manage router** or **Sign in to network**.
- If a computer opens a Microsoft connectivity page, gets stuck, or does not display Scoopy's captive portal correctly, use a phone or tablet for setup.
- Re-check the home Wi-Fi password before pressing **Connect Scoopy**.

If Scoopy previously worked on another Wi-Fi network, hold both buttons together for 10 seconds to clear the saved Wi-Fi details and return it to setup mode.

See [`setup.md`](setup.md) for the full onboarding flow.

## Button input problems

Each physical button is exposed to Home Assistant as an event entity supporting:

- `single`
- `double`
- `hold`

If a button appears not to work:

- Open the Scoopy device in Home Assistant and confirm **Button 1** and **Button 2** are present.
- Use the event entity or an automation trace to confirm which event is being received.
- Check that your automation is using the actual Entity ID assigned by Home Assistant, including any area prefix.
- If you built the hardware yourself, inspect the tactile switch soldering and make sure the printed button moves freely and is not permanently pressing the switch.
- Avoid holding both buttons together for 10 seconds unless you intend to factory-reset Wi-Fi.

The GitHub examples in [`examples.md`](examples.md) show the expected Home Assistant event-trigger format.

## LED behaviour

Normal built-in status behaviour is:

- **Middle red LED pulsing:** Scoopy is waiting for Wi-Fi or has lost its Wi-Fi connection.
- **Brief green confirmation:** Scoopy has successfully connected to Wi-Fi.
- **LEDs off after connection:** normal idle state unless Home Assistant or an automation is controlling them.

Home Assistant exposes three individual LED entities plus the coordinated **LED Pattern** entity.

If an effect behaves unexpectedly:

- Check whether an individual LED and **LED Pattern** are being controlled by different automations at the same time.
- Turning on an individual LED stops the coordinated pattern first, and starting a coordinated pattern takes ownership of all three LEDs.
- Check the automation trace for repeated `light.turn_on`, `light.turn_off`, or effect actions.

If one physical LED never lights, inspect its orientation, soldering, series resistor, and light-pipe alignment. V1 uses 2.2 kΩ series resistors for the LEDs.

## mmWave radar connection and detection

### Scoopy Compact

Scoopy Compact does not have an LD2410C fitted. Because Compact and Presence use the same firmware, radar entities may show as unavailable or **Unknown**. This is expected.

### Scoopy Presence

On Scoopy Presence, Home Assistant should expose **Presence**, **Moving Target**, and **Still Target**.

If those entities remain unavailable or detection is poor:

- Give the LD2410C a few seconds after boot to begin reporting normally.
- Check that the radar is fitted securely and correctly connected to the carrier PCB.
- The firmware UART uses GPIO1 as ESP TX to LD2410 RX and GPIO0 as ESP RX from LD2410 TX.
- Check the UART solder joints and wiring if you are building from the source hardware files.
- Use a nylon M2 screw near the radar where possible. A metal screw may affect the LD2410C, which is why the Presence assembly guide recommends nylon.
- Make sure the enclosure is assembled in the correct orientation and nothing metallic has been added directly in front of or beside the radar unnecessarily.

The standard V1 firmware intentionally keeps the core presence entities simple. High-frequency distance entities are disabled by default to avoid filling Home Assistant Recorder history with constantly changing measurements.

## Bluetooth Proxy problems

Bluetooth Proxy is optional and starts switched off.

If Scoopy is not appearing as a Bluetooth Proxy:

- Open the Scoopy device in Home Assistant and turn on **Bluetooth Proxy** under Configuration.
- Check that Home Assistant is currently connected to Scoopy through ESPHome.
- Go to **Settings → Bluetooth → My network → Adapters** and look for Scoopy.
- Scoopy uses passive BLE scanning and provides one active proxy connection slot, so `1/1` connections simply means that slot is currently in use.
- If Home Assistant disconnects from Scoopy, BLE scanning deliberately stops. It resumes when Home Assistant reconnects if the Bluetooth Proxy switch is still enabled.

On Scoopy Presence, Home Assistant may also discover the onboard LD2410C over BLE. That separate LD2410 BLE integration is optional because Scoopy already reads the radar directly over UART for its normal presence entities.

## Firmware update problems

Released firmware updates appear through the **Firmware Update** entity in Home Assistant.

If an update does not complete:

- Confirm Scoopy is online and has a stable Wi-Fi connection.
- Retry the update from the **Firmware Update** entity.
- Avoid removing power while firmware is actively being written.
- After a successful update, Scoopy reboots automatically and should return with the same device identity, Wi-Fi credentials, and Home Assistant entities.
- Check the **Scoopy Firmware** diagnostic entity to confirm the installed version.

Native ESPHome OTA and USB flashing remain available for development or recovery if required.

## I²C expansion problems

The production firmware enables an I²C bus on:

- GPIO5 — SDA
- GPIO7 — SCL

I²C scanning is enabled, so detected addresses should appear in ESPHome logs.

If an expansion device is not detected:

- Re-check SDA, SCL, ground, and power connections against the V1 KiCad schematic before applying power.
- Confirm the peripheral is compatible with the electrical levels provided by your build.
- Check for an address conflict if more than one I²C device is fitted.
- Check whether the peripheral already includes pull-up resistors and whether your overall bus has suitable pull-ups.
- Keep wiring short while diagnosing the problem.
- Watch the ESPHome logs during boot for the I²C scan result.

The I²C connection is intended for user expansion, so any additional ESPHome component configuration for your chosen peripheral is your responsibility.

## USB-C fit or enclosure alignment

If the enclosure does not close cleanly:
- Check that the two printed buttons are seated correctly in the lid.
- Make sure the USB-C connector is correctly seated through the opening in the base before tightening the PCB screw.
- Confirm the three lid light pipes line up with the three PCB LEDs before clipping the base into the lid.
- Check that the heat-set insert is straight and the M2 screw is not pulling the PCB out of position.

For raw geometry, use the versioned STL exports in [`../enclosure/`](../enclosure/).

For Bambu Studio / 3MF printing, use the maintained [Scoopy MakerWorld project](https://makerworld.com/en/models/3231250-scoopy-home-assistant-esphome-room-controller#profileId-3659818). The slicer project is intentionally maintained there rather than duplicated in GitHub.

## Factory reset and start again

If setup is badly confused or you are moving Scoopy to a new Wi-Fi network:

1. Hold both physical buttons together for 10 seconds.
2. The middle red LED flashes rapidly near the end of the hold.
3. Scoopy clears its saved Wi-Fi credentials.
4. After reboot, the red LED pulses and `scoopy-XXXXXX` returns.
5. Follow [`setup.md`](setup.md) again.

A factory reset clears Wi-Fi setup; it does not require you to reflash the firmware.

## Still stuck?

Check the illustrated setup guide at https://nicehatthanks.com/setup/ and the interactive documentation at https://nicehatthanks.com/docs/.

For project files and technical history, use the GitHub repository. For direct help, use https://nicehatthanks.com/contact.html.

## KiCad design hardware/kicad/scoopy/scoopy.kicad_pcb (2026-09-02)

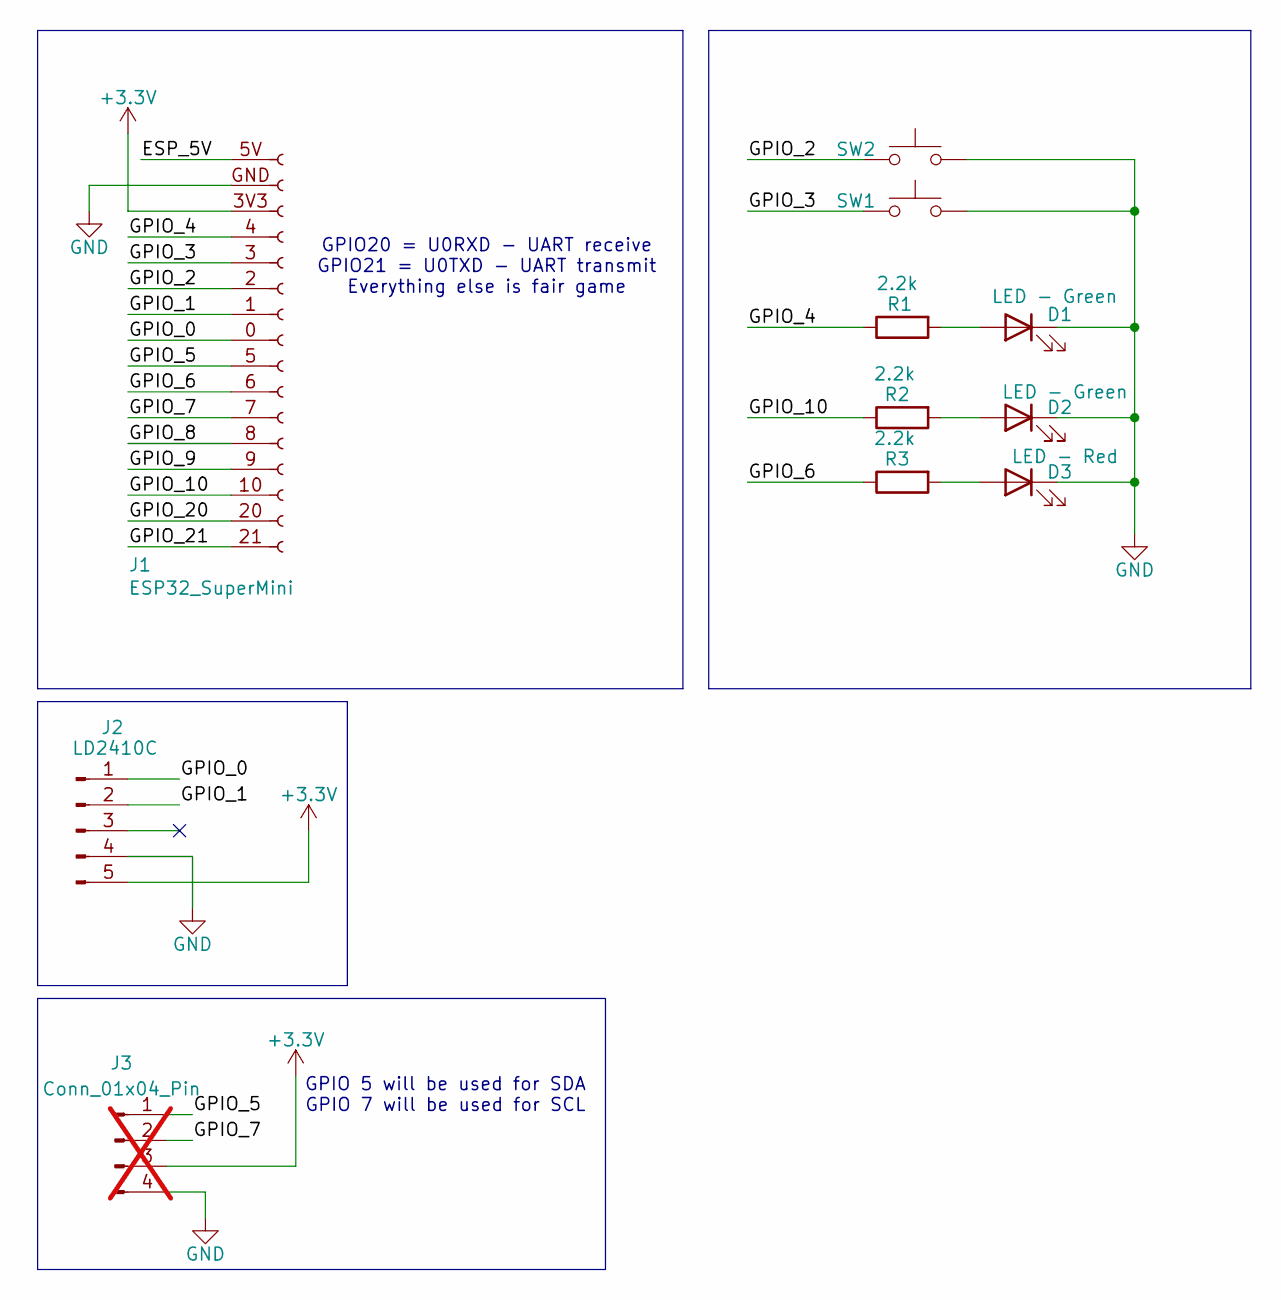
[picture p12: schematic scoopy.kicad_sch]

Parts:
D1, D2: LED - Green; LED_0603_1608Metric; MPN C22371297
D3: LED - Red; LED_0603_1608Metric; MPN C19171390
J1: ESP32_SuperMini; ESP32-C3-SuperMini
J2: LD2410C; Ld2410c; MPN C19723500
J3: Conn_01x04_Pin; PinHeader_1x04_P2.54mm_Vertical; not fitted
R1, R2, R3: 2.2k; R_0603_1608Metric; MPN C2907005
SW1, SW2: SW_Push; SW_SPST_TL3305C; MPN C879462

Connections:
+3.3V: J1.3V3 (Pin_3), J2.5, J3.3
/ESP_5V: J1.5V (Pin_1)
/GPIO_0: J1.0 (Pin_8), J2.1
/GPIO_1: J1.1 (Pin_7), J2.2
/GPIO_2: J1.2 (Pin_6), SW2.1
/GPIO_3: J1.3 (Pin_5), SW1.1
/GPIO_4: J1.4, R1.1
/GPIO_5: J1.5 (Pin_9), J3.1
/GPIO_6: J1.6 (Pin_10), R3.1
/GPIO_7: J1.7 (Pin_11), J3.2
/GPIO_8: J1.8 (Pin_12)
/GPIO_9: J1.9 (Pin_13)
/GPIO_10: J1.10 (Pin_14), R2.1
/GPIO_20: J1.20 (Pin_15)
/GPIO_21: J1.21 (Pin_16)
GND: D1.1 (K), D2.1 (K), D3.1 (K), J1.GND (Pin_2), J2.4, J3.4, SW1.2, SW2.2
unnamed: D1.2 (A), R1.2
unnamed: D2.2 (A), R2.2
unnamed: D3.2 (A), R3.2

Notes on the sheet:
GPIO 5 will be used for SDA GPIO 7 will be used for SCL
GPIO20 = U0RXD - UART receive GPIO21 = U0TXD - UART transmit Everything else is fair game

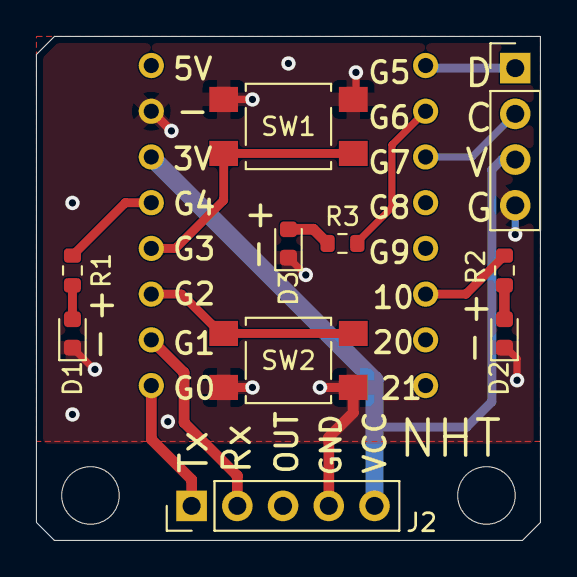
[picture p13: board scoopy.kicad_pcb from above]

Board: 2 copper layers, 28.0 x 28.0 mm, 11 parts (1 on the bottom side), 14 nets.

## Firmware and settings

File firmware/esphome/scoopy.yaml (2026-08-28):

# ============================================================
# Scoopy Node - Unified Firmware
# ============================================================
#
# Hardware:
#
#   GPIO0  - LD2410C TX to UART RX
#   GPIO1  - LD2410C RX to UART TX
#   GPIO2  - Button 1
#   GPIO3  - Button 2
#   GPIO4  - Left green LED
#   GPIO5  - I2C SDA
#   GPIO6  - Middle red LED
#   GPIO7  - I2C SCL
#   GPIO10 - Right green LED
#
# The same firmware is intended for both:
#
#   Scoopy Compact
#   Scoopy Presence
#
# If an LD2410C is not fitted, its entities will remain Unknown
# while the rest of Scoopy continues operating normally.
#
# First-time setup:
#
#   1. Device creates a Wi-Fi AP named scoopy-XXXXXX
#   2. Customer connects using password: scoopy123
#   3. Captive portal is used to enter home Wi-Fi credentials
#   4. Home Assistant discovers Scoopy through ESPHome
#
# Recovery:
#
#   Hold both buttons for 10 seconds to factory-reset Wi-Fi
#   credentials and return Scoopy to setup mode.
#
# ============================================================


# ============================================================
# Device identity
# ============================================================

esphome:
  name: scoopy
  friendly_name: Scoopy

  # Adds the final six hexadecimal digits of the ESP32 MAC
  # address to the device name.
  #
  # Example:
  #   scoopy-2176d8
  #
  # This gives every Scoopy a unique identity while allowing
  # every device to use exactly the same firmware image.
  name_add_mac_suffix: true

  # Nice Hat Thanks firmware identity. This is separate from the
  # ESPHome framework version and lets Home Assistant show the
  # Scoopy firmware release installed on the device.
  project:
    name: "nicehatthanks.scoopy"
    version: "1.0.0"

  # Start the red setup pulse once components have initialised.
  # If Wi-Fi is already connected, leave the LEDs off.
  on_boot:
    priority: -100
    then:
      - if:
          condition:
            not:
              wifi.connected:
          then:
            - light.turn_on:
                id: middle_led
                brightness: 100%
                effect: "Pulse Bright"


# ============================================================
# ESP32-C3
# ============================================================

esp32:
  board: esp32-c3-devkitm-1
  framework:
    type: esp-idf


# ============================================================
# Scoopy custom components
# ============================================================

# Override only ESPHome's captive_portal component so Scoopy
# can use the branded setup page while retaining ESPHome's
# normal Wi-Fi storage, DNS and captive-portal behaviour.
external_components:
  - source:
      type: local
      path: components
    components:
      - captive_portal


# ============================================================
# Logging / Home Assistant / OTA
# ============================================================

logger:

api:

  # The ESP32-C3 is single-core, so Wi-Fi and BLE scanning
  # share CPU/radio time. Only run BLE scanning while a
  # Home Assistant state-subscribing API client is connected
  # and the customer has enabled the Bluetooth Proxy switch.
  on_client_connected:
    - if:
        condition:
          and:
            - switch.is_on: bluetooth_proxy_enabled
            # on_client_connected fires before Home Assistant has
            # necessarily subscribed to entity states, so identify
            # the HA client directly rather than racing that subscription.
            - lambda: |-
                return client_info.rfind("Home Assistant", 0) == 0;
        then:
          - esp32_ble_tracker.start_scan:
              continuous: true

  # This trigger also fires for short-lived clients such as the
  # ESPHome log viewer. Only stop scanning when no Home Assistant
  # state-subscribing API client remains connected.
  on_client_disconnected:
    - if:
        condition:
          not:
            api.connected:
              state_subscription_only: true
        then:
          - esp32_ble_tracker.stop_scan:


# ============================================================
# Bluetooth LE / Home Assistant Bluetooth Proxy
# ============================================================

# Use passive BLE scanning to minimise Wi-Fi/BLE contention on the
# single-core ESP32-C3.
#
# Continuous scanning is disabled at component startup so BLE does
# not compete with Wi-Fi while Scoopy is booting or being provisioned.
# The Home Assistant switch below starts a continuous passive scan
# only while Home Assistant is connected. Default ESPHome scan
# interval/window values are deliberately retained for Wi-Fi stability.
esp32_ble_tracker:
  scan_parameters:
    active: false
    continuous: false
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

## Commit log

2026-08-19 Add assembly documentation skeleton
2026-08-19 Add enclosure folder guide
2026-08-20 Add Scoopy KiCad hardware design and fabrication files
    [scoopy-B_Cu.gbl, scoopy-B_Mask.gbs, scoopy-B_Paste.gbp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]
2026-08-20 Tidy hardware source and fabrication layout
    [scoopy-B_Cu.gbl, scoopy-B_Mask.gbs, scoopy-B_Paste.gbp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]
2026-08-20 Moved gerber files
2026-08-20 Prepare enclosure folder for printable releases
2026-08-20 Add V1 full enclosure STL folder
2026-08-20 Add V1 enclosure parts STL folder
2026-08-20 Add V1 3MF enclosure folder
2026-08-20 Update repository structure for printable enclosure files
2026-08-20 Split enclosure layout into compact and presence variants
2026-08-20 Document compact and presence enclosure variants
2026-08-20 Add compact enclosure print folders
2026-08-20 Add compact enclosure parts folder
2026-08-20 Add compact enclosure 3MF folder
2026-08-20 Add presence enclosure print folders
2026-08-20 Add presence enclosure parts folder
2026-08-20 Add presence enclosure 3MF folder
2026-08-20 Remove superseded shared enclosure folders
2026-08-20 Remove superseded shared enclosure parts folder
2026-08-20 Remove superseded shared enclosure 3MF folder
2026-08-20 Add V1 compact and presence enclosure files
    [scoopy-compact-v1-base.stl, scoopy-compact-v1-button1.stl, scoopy-compact-v1-button2.stl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]
2026-08-20 renaming files for consistency :D
    [scoopy-compact-v1-lightpipe-1.stl, scoopy-compact-v1-lightpipe-2.stl, scoopy-compact-v1-lightpipe-3.stl]
2026-08-21 Add initial ESPHome button prototype
2026-08-21 Add Scoopy captive portal UI prototype
2026-08-21 Load Scoopy captive portal device and Wi-Fi data
2026-08-21 Wire Scoopy onboarding Wi-Fi submission
2026-08-21 Add ESP32 captive DNS header
2026-08-21 Add ESP32 captive DNS implementation
2026-08-21 Use single Scoopy config and restore setup LED pulse
2026-08-21 docs: document current ESPHome firmware
2026-08-23 fix: report wifi state and redirect captive probes
2026-08-23 More schem info on kicad
    [scoopy-presence-v1.3mf, scoopy.kicad_pcb, scoopy.kicad_sch]
2026-08-24 Swapped LD2410C RX TX to match PCBA :D
    [scoopy.yaml]
2026-08-24 Added easy method to remove PCBA from Scoopy
    [scoopy-presence-v1-base.stl]
2026-08-24 larger dia in buttons
    [scoopy-presence-v1-button1.stl, scoopy-presence-v1-button2.stl]
2026-08-24 Add lots of led patterns. fimrware version and wifi diagnostics for HA. Possibility for ota updates via website
2026-08-25 docs: add device traceability architecture
2026-08-25 scoopy now turns off all LEDs before running an effect
2026-08-28 Updated stl for strong side clips
    [scoopy-compact-v1-base.stl, scoopy-compact-v1-button1.stl, scoopy-compact-v1-button2.stl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]
2026-08-28 update scoopy v1.5
    [scoopy-compact-v1.3mf, scoopy-presence-v1-base.stl, scoopy-presence-v1.3mf]
2026-08-28 1k Res was too bright for LEDs. Changed to 2.2k
    [scoopy.kicad_pcb, scoopy.kicad_sch, scoopy_eBOM.csv]
2026-08-28 docs: add Scoopy V1 assembly guide
2026-08-28 docs: resize assembly images
2026-08-28 docs: point enclosure projects to MakerWorld
2026-08-28 docs: link assembly guide to MakerWorld
2026-09-02 Updated proper ESP32-C3 supermini in eBOM
    [scoopy.kicad_pcb, scoopy.kicad_sch, scoopy_eBOM.csv]
